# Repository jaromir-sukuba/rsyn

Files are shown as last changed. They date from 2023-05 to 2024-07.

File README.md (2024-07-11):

# What is in this repository?
Here is the complete set of design files, BOM, source files, test results and other resources that I used in the process of building a simple resistance synthesizer.

# What is resistance synthesizer?
A resistance synthesizer is a device allowing the emulation of a resistance or (nearly) any value for use in control and test instrumentation. It can emulate resistive components like resistive temperature devices (thermistors, platinum sensors) or other resistive sensors, too. There are commercial instruments that do this task, but they are often way outside the average hobby budget. Therefore, I decided to build one.

This project demonstrates a simple resistance synthesizer device built around a high-precision digital-to-analog converter (DAC) that is controlled by a microcontroller, allowing communication with a computer to control and calibrate the instrument, allowing integration into automated test setups. As standard in test equipment, the analog portion of the instrument is isolated from the digital portion, which makes the integration much easier as the synthesizer doesn't suffer from ground loops and is insulated from potentially dangerous voltage levels. Apart from control via USB, the instrument contains a local user interface consisting of a keypad and display.
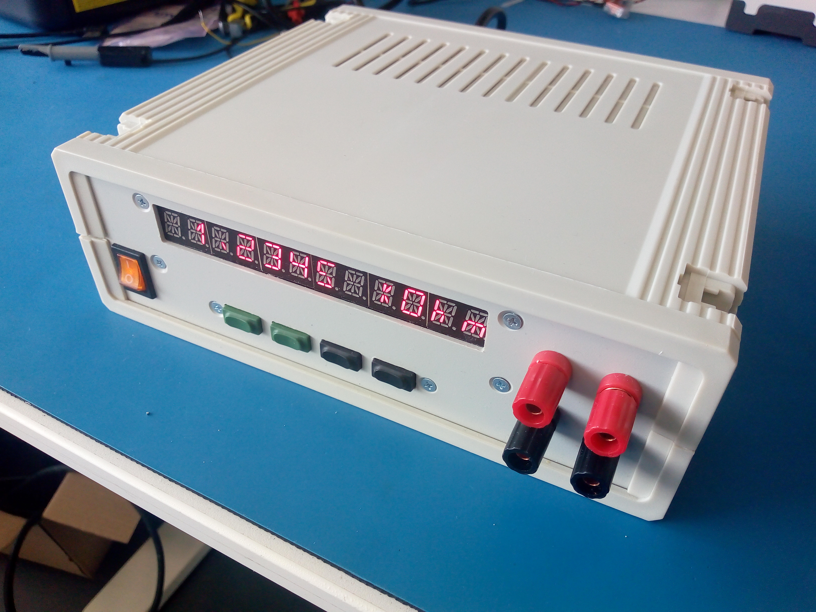
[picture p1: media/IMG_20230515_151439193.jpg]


# How does resistance synthesis work?
Reistance synthesis can be done in numerous ways. The obvious one is a network of resistors and relays to switch the desired value. The number of relays and resistors can be minimized by varying exponential values and switching in binary code patterns. That would employ resistor values of 1R-2R-4R-8R-16,  etc., and an appropriate switching pattern allowing the resistor to be included or excluded from the circuit. This approach is quite straightforward but has a few issues. Contact resistance is included in the resistor value and can matter, especially on the low end of the range (unless a four-wire arrangement is used, which can solve most of the contact problems); the contact resistance may change over the relay lifetime and other environmental factors. Furthermore, switching takes time, may be acoustically noisy, and causes relay contact wear.
More elegant is the electrical resistance adjustment. Digital potentiometers may be adequate for many uses, but they usually suffer from low resolution and low precision. While those can be a perfect fit for many applications, my idea of a resistance synthesizer requires somehow a more nuanced approach.
Fortunately, there are other ways to emulate the resistance, reducing the problem to current sensing and voltage generation, both of which can be done relatively easily and with much higher precision than the digital potentiometer can offer.
The principle is simple and this picture demonstrates this approach. 
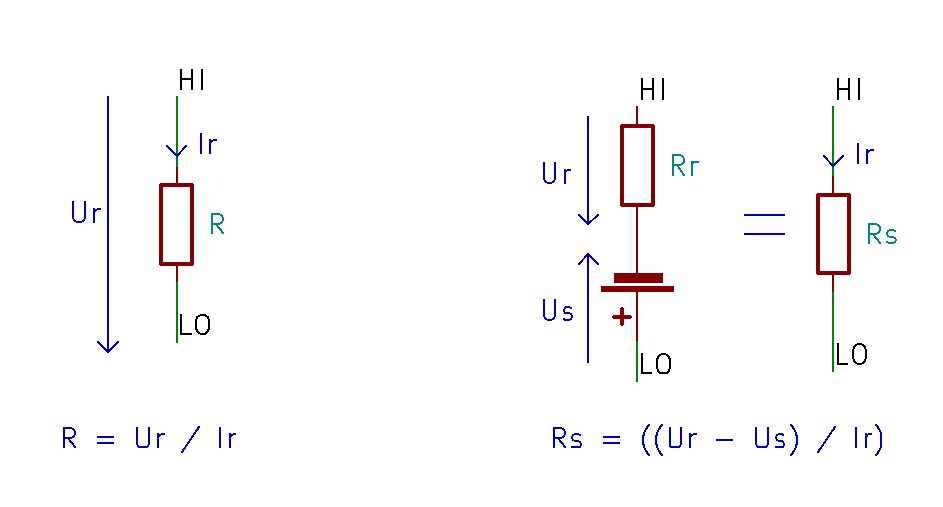
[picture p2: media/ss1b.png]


The left side of the picture captures voltage and current in a simple circuit with a resistor, following Ohm's law. Should we include voltage source U in series with the resistor, the apparent resistance of the circuit changes, following the formula on the right side of the picture. If the Us is derived from the current Ir, the resulting resistance value is invariant of the current Ir, so that the circuit behaves like a resistor with apparent resistance Rs between zero (Us = Ir x Rr) and Rr (Us = 0). 

Second picture depicts this idealized schematic in a way that somehow resembles the circuit in my resistance synthesizer. 
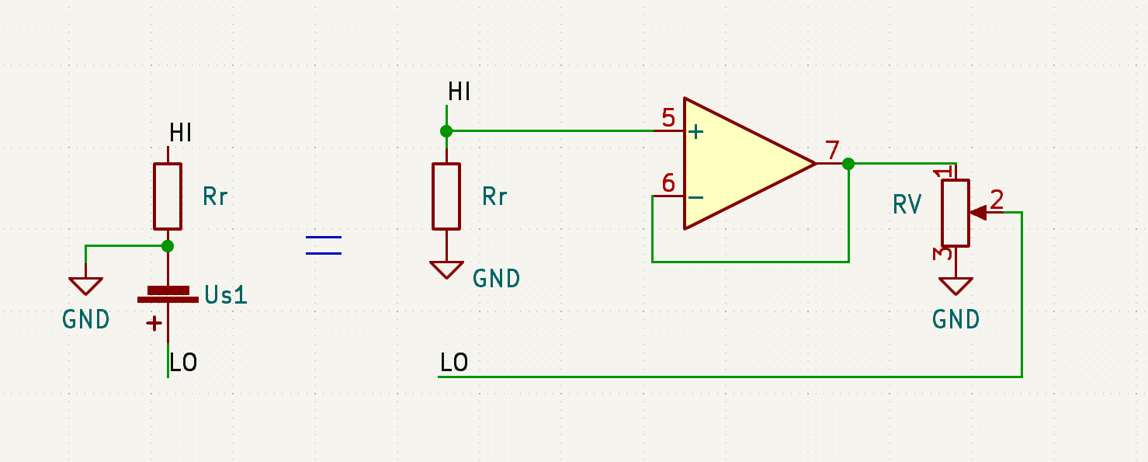
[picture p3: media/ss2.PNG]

The voltage on Rr is brought to a voltage follower (so that Ir isn't influenced by following circuits) and subsequently to a potentiometer, allowing it to regulate the synthesized resistance value. This circuit has the advantage of a potentiometer acting like a grounded voltage divider, so it can be substituted by a multiplying DAC, in this case LTC2756.

# Instrument overview
Schematic sheet 'Interconnect' depicts top-level schematics and internal instrument wiring.
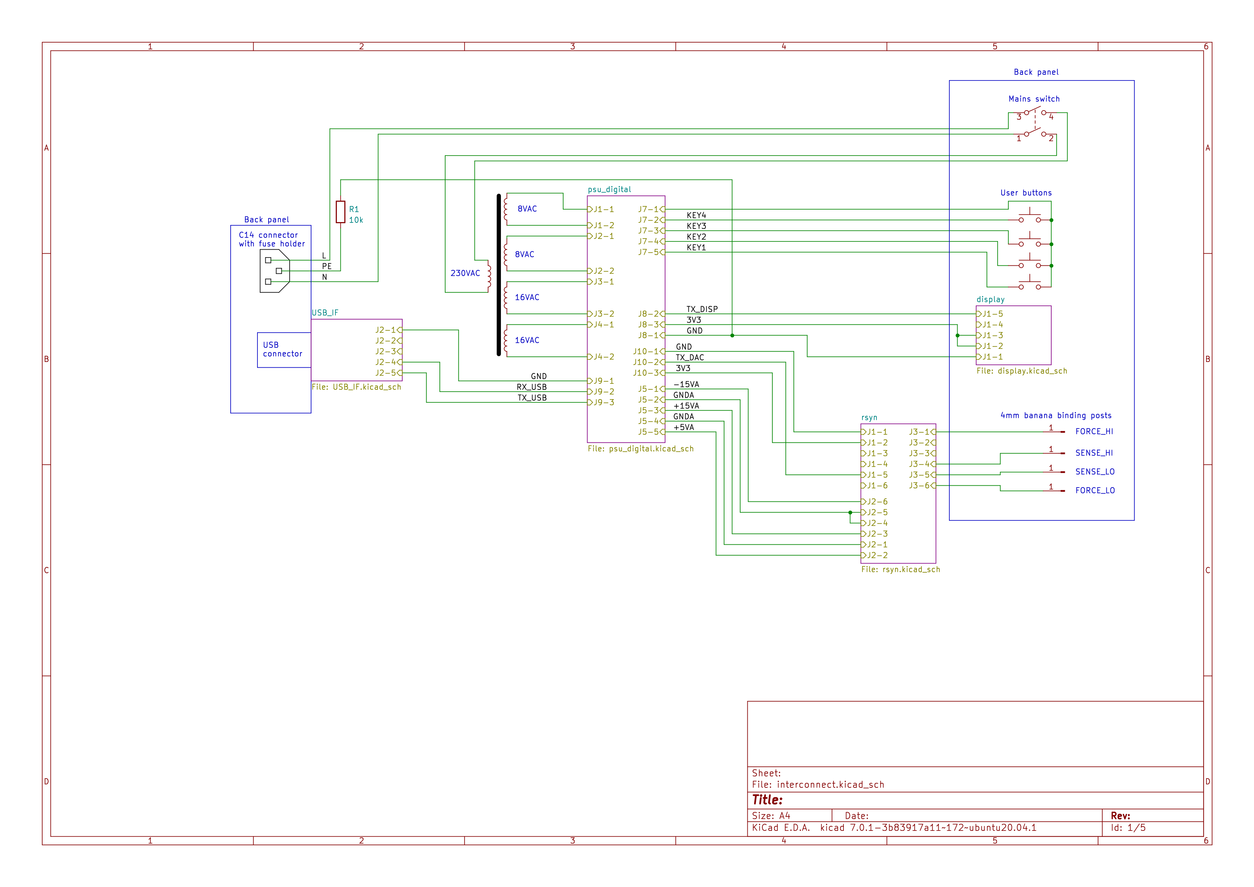
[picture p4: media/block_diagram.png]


## Resistance synthesizer board
Reference resistors R19 and R29/30 are switched using DG442 analog switches U11C and U11D. There are options to change the gain of the reference resistor amplifier (R20, R24, R28, and U7B, U11A, and U11B) and DAC amplifier (R8, R9, R10, and switches U7A, U7C, and U7D), but those aren't used in the current firmware, so that U7A and U7B are switched continuously.
U4 is the heart of the resistance synthesizer board. It works in a more-or-less datasheet configuration, with one interesting point: its reference voltage is switchable by zero-ohm resistors R2 and R3 (only one is installed). When R2 is populated, the output works in the range 0..5 V and is useful for testing the DAC. In this mode, the circuit doesn't work as a resistance synthesizer. When R3 is installed instead of R2, the reference voltage is derived from the resistance drop on a reference resistor (refer to Picture #2), and the circuit works as a resistance synthesizer.
The remaining parts of the PCB are just support functions for the DAC. Microcontroller U10 acts as a UART-DAC bridge, converting ASCII commands from serial lines to DAC SPI control packets and analog switch actions. U3 acts as a digital isolator, allowing the digital and analog boards to be separated electrically.

## Display board
Three SCT2024 shift registers with constant current drivers are chained into a 48-bit-long string. Six pieces of dual starburst LED displays are multiplexed in a 1:4 multiplex ratio by the microcontroller U7. This microcontroller communicates via serial line and transforms single ASCII commands into text readable on the display.

## Digital and PSU boards
U5 on this board acts as the main controlling element of the device. It talks to internal microcontrollers (on the resistance synthesizer board and display board) as well as external communication channels via USB. Apart from that, it reads the keyboard to allow direct user control. The majority of the complexity of this part lies in firmware, available on GitHub.
PSU is relatively straight-forward. Both analog and digital sections are fed from separate transformer windings, each with a diode rectifier and voltage regulator. In the case of the digital section, I opted for a Murata OKI-78-SR-33 switching regulator to cut down on heat generated in the PSU.

# Physical construction
Resistance synthesizers and display boards were designed as 4-layer PCBs in KiCAD. Digital PSU and keypad boards were simple enough to be made on a perfboard.
All electrical components are mounted into a CP-15-32 enclosure with custom milled front and back panels. Construction is obvious from the photos.
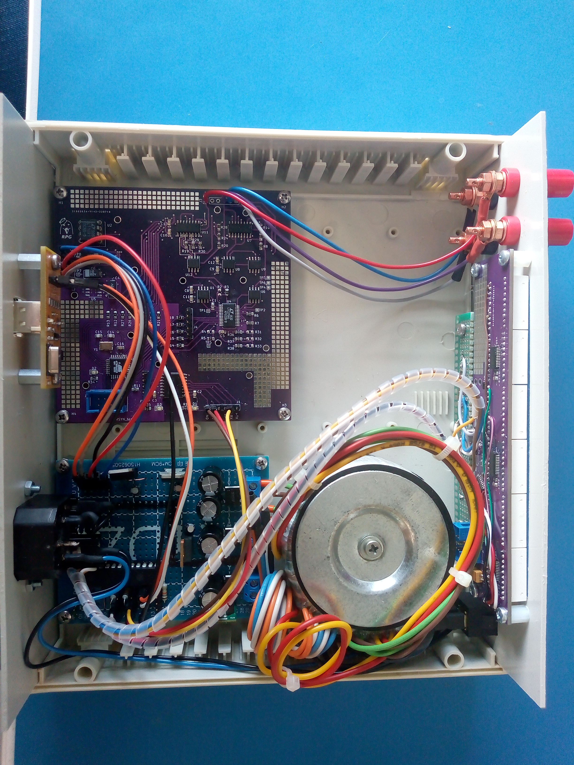
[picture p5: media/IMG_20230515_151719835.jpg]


# Instrument operation
It is operated using either a local interface or serial commands. For the local interface, keys 1 and 2 select the digit to be modified, and keys 3 and 4 perform incrementation or decrementation of the digit. The digit to be modified blinks for approximately 4 seconds. Pressing keys 1 and 2 simultaneously changes the range (10 and 100 kOhm ranges).
For the serial interface, the following commands are implemented in current firmware:

### idn
returns instrument identification
PC->Instrument: idn<LF>
Instrument->PC: RSYN Ver 1.00<LF>

### srv
set resistance value
PC->Instrument: srv 1.234LF>
Instrument->PC: srv 1.234LF>

### grv
set resistance value
PC->Instrument: grv<LF>
Instrument->PC: grv 1.234LF>

### srr
set resistance range (0: 0-10 kOhm; 1: 0-100 kOhm)
PC->Instrument: srr 1LF>
Instrument->PC: srr 1LF>

### grr
Get the resistance range (0: 0-10 kOhm; 1: 0-100 kOhm).
PC->Instrument: grr<LF>
Instrument->PC: grr 1LF>

### scc 
Set the calibration coefficient (the first argument is the coefficient number, the second is the coefficient).
PC->Instrument: scc 2, 3.456LF>
Instrument->PC: scc 2, 3.456LF>

### gcc 
Get the calibration coefficient (the argument is the coefficient number).
PC->Instrument: gcc 2LF>
Instrument->PC: gcc 2, 3.456LF>

### gcd
get a calibration dump
PC->Instrument: gcd<LF>
Instrument->PC: gcc [followed by calibration constants on each line] <LF>

### wmc
write calibration coefficient (into EEPROM memory; previous calibration is overwritten)
PC->Instrument: wcc<LF>
Instrument->PC: wcc<LF>

After first powering up, default calibration constants 0 and 12345 are loaded for offset and gain, respectively. The user needs to replace those constants with valid ones obtained by calibration. For calibration, a ohmmeter, usually in a form of multimeter has to be used. The precision of the resistance synthesizer is determined by he meter used for adjustment. On the other hand, thermal and long time drift is given by design and construction of the device.
The calibration procedure is as follows:
1. Turn on the calibration meter and resistance synthesizer, connect the appropriate leads, and let them warm up (typical precision meters do have a few hours of warmup required).
2, set the meter to the 10 kOhm manual range, set the synthesizer to the 10 kOhm range, and set the synthesizer to 50 kOhm. Adjust the offset to range 0 so that the meter correctly displays 50 ohms.
3. Set the synthesizer to 10 kOhm. Adjust gain at range 0 so that the meter correctly displays 10 kOhm.
4. Repeat steps 2 and 3 if needed.
5, do the same as step 2 on 100 kOhm ranges and adjust offset at range 1.
6. Do the same as step 3, with a 100 kOhm value, and adjust gain at range 1.
7. Repeat steps 4 and 5 if needed.
8. Issue the wmc command to overwrite previous calibration values in the EEPROM.

## Verification
For parameter verification, I performed two tests: a linearity check and short-term stability. 
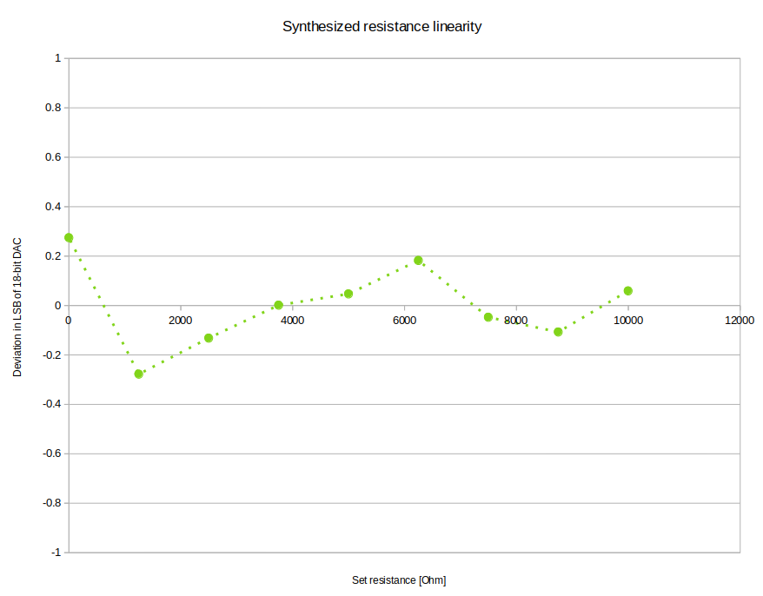
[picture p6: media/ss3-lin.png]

For the linearity test, I set the values of the DAC converter to values from 0 to 262143 in increments of 32768. I measured the resitance values using an HP34401A multimeter and calculated the difference from the linear fit of the values, expressed in the least significant digits of the value. As apparent from the graph, the typical deviation from linearity is around 0.2 LSB, indicating that the used DAC has very good linearity, and apart from that, linearity isn't degraded by the analog functionality (chosen opamps and reference resistors).
Short-term stability: I measured the value of resistance set to 5 kOhm over the course of one hour. The value was stable within the 20 mOhm range. 
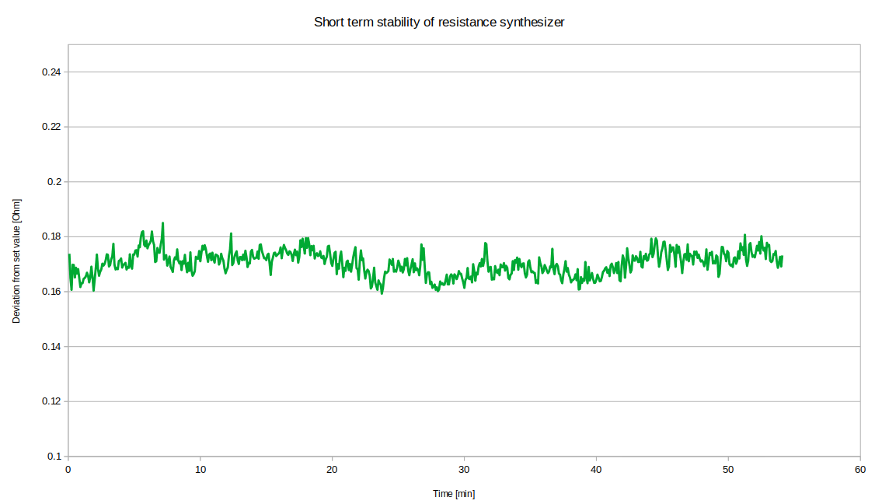
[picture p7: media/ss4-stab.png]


# Resources
A video showing the synthesizer in operation is at https://youtu.be/5EVBY4_3-oE

# Resume
This resistance synthesizer is not a very common target of DIY designs, but nonetheless, it's a useful tool for automatic calibration of test and measurement instruments or as a general-purpose tool for testing and adjusting multimeters, controllers, and similar apparatus.

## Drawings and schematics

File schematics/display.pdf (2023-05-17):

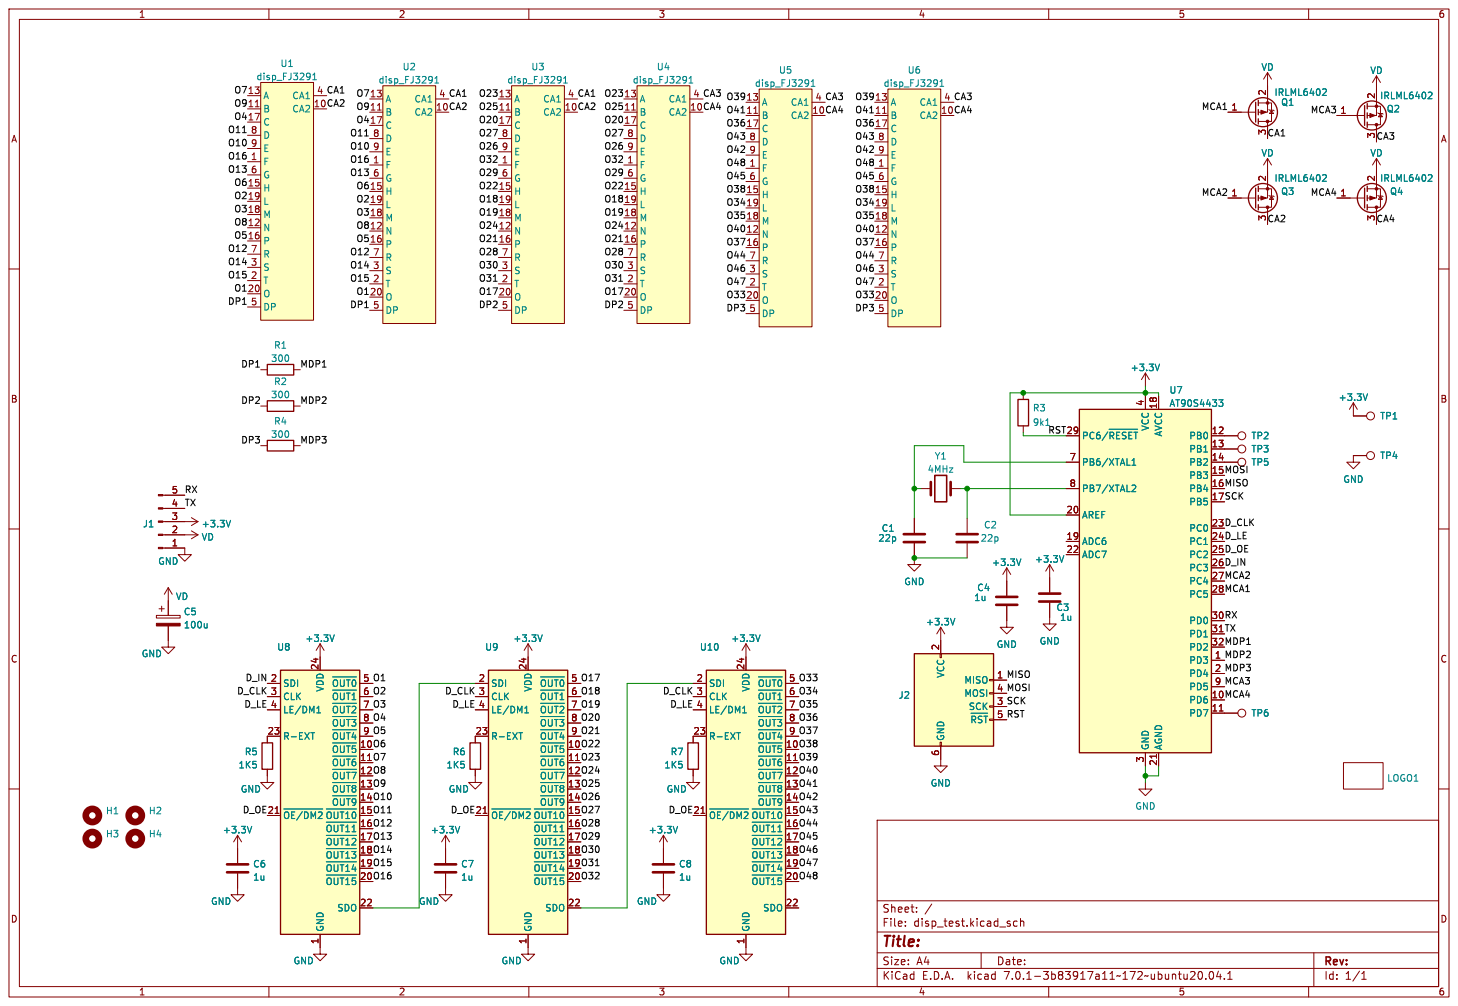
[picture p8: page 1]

2 SCK 3 MOSI 4 ~{RST}5 GND

1 ~{OUT5} 10 ~{OUT6} 11 ~{OUT7} 12 ~{OUT8} 13 ~{OUT9} 14 ~{OUT10}15 ~{OUT11}16 ~{OUT12}17 ~{OUT13}18 ~{OUT14}19 SDI 2 ~{OUT15}20 ~{OE/DM2} 21 SDO 22 R-EXT 23 VDD 24 CLK 3

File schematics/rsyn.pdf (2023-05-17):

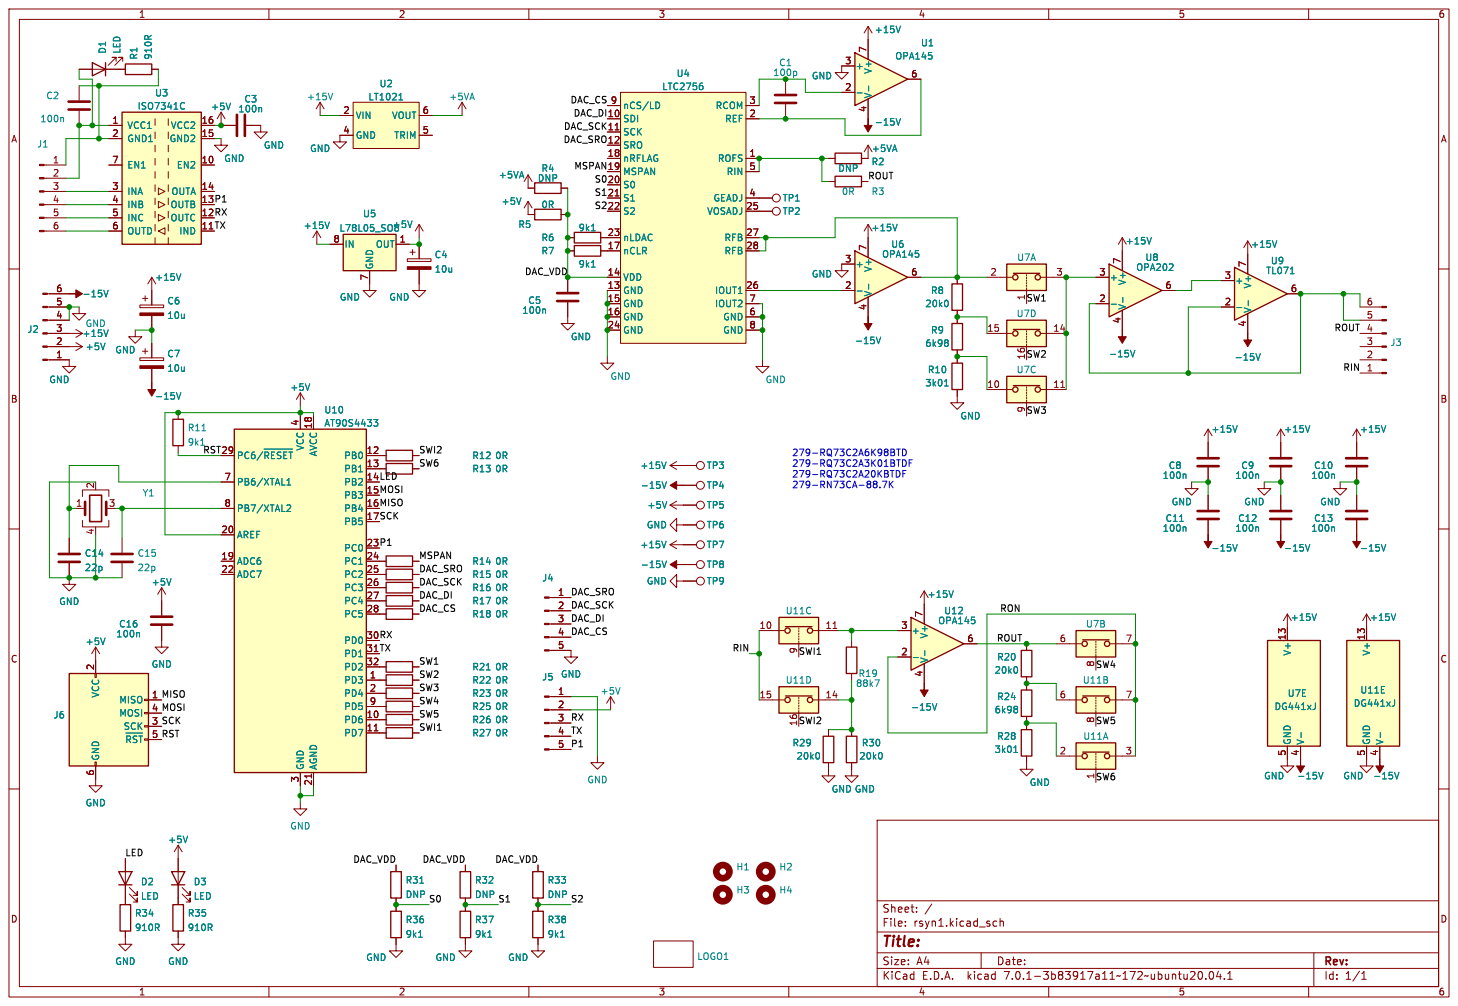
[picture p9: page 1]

IND 11 OUTC 12 OUTB 13 OUTA 14 GND2 15 VCC2 16 GND1 2

2 SCK 3 MOSI 4 ~{RST}5 GND

5 GND -15V GND -15V GND GND

Id: 1/1 Title: File: rsyn1.kicad_sch Sheet: /

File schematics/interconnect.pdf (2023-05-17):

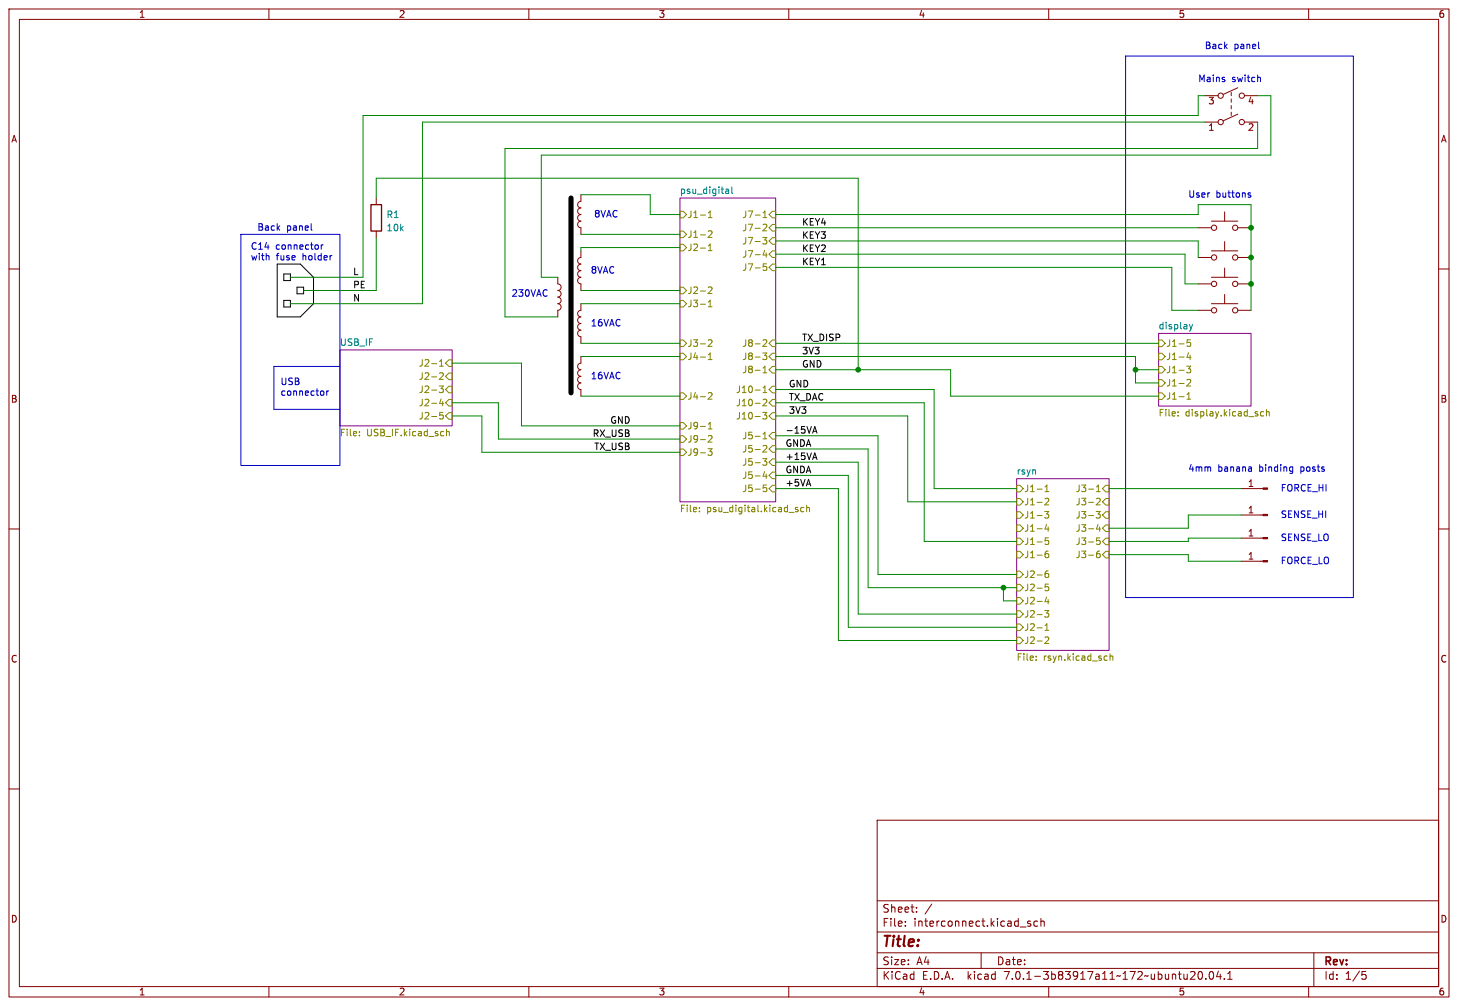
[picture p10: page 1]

C14 connector with fuse holder USB

Id: 1/5 Title: File: interconnect.kicad_sch Sheet: /

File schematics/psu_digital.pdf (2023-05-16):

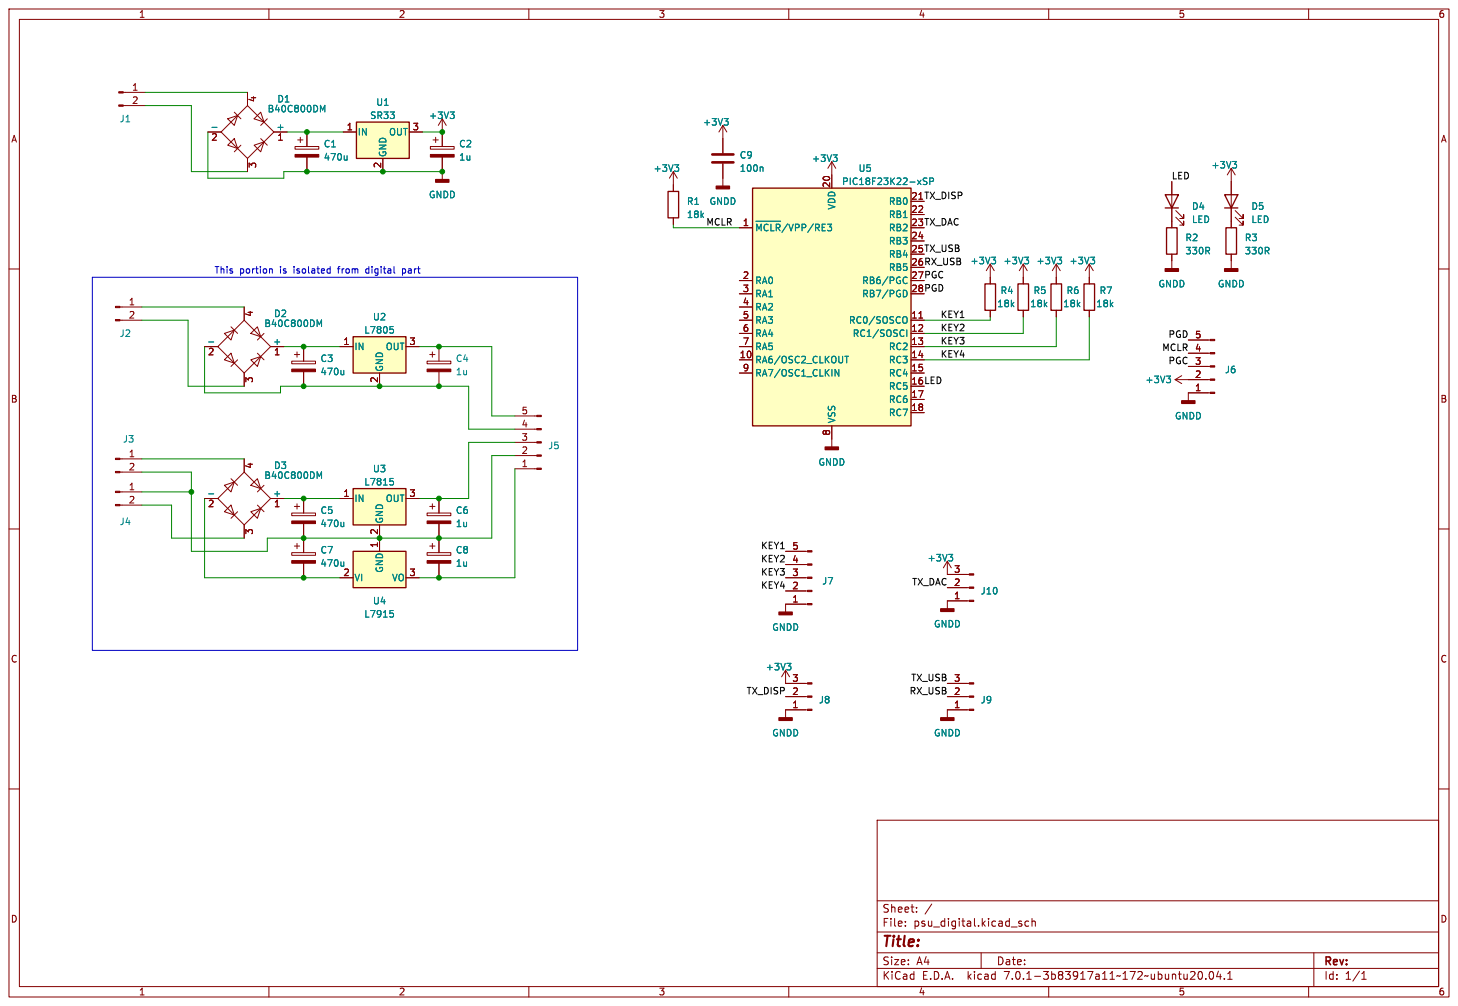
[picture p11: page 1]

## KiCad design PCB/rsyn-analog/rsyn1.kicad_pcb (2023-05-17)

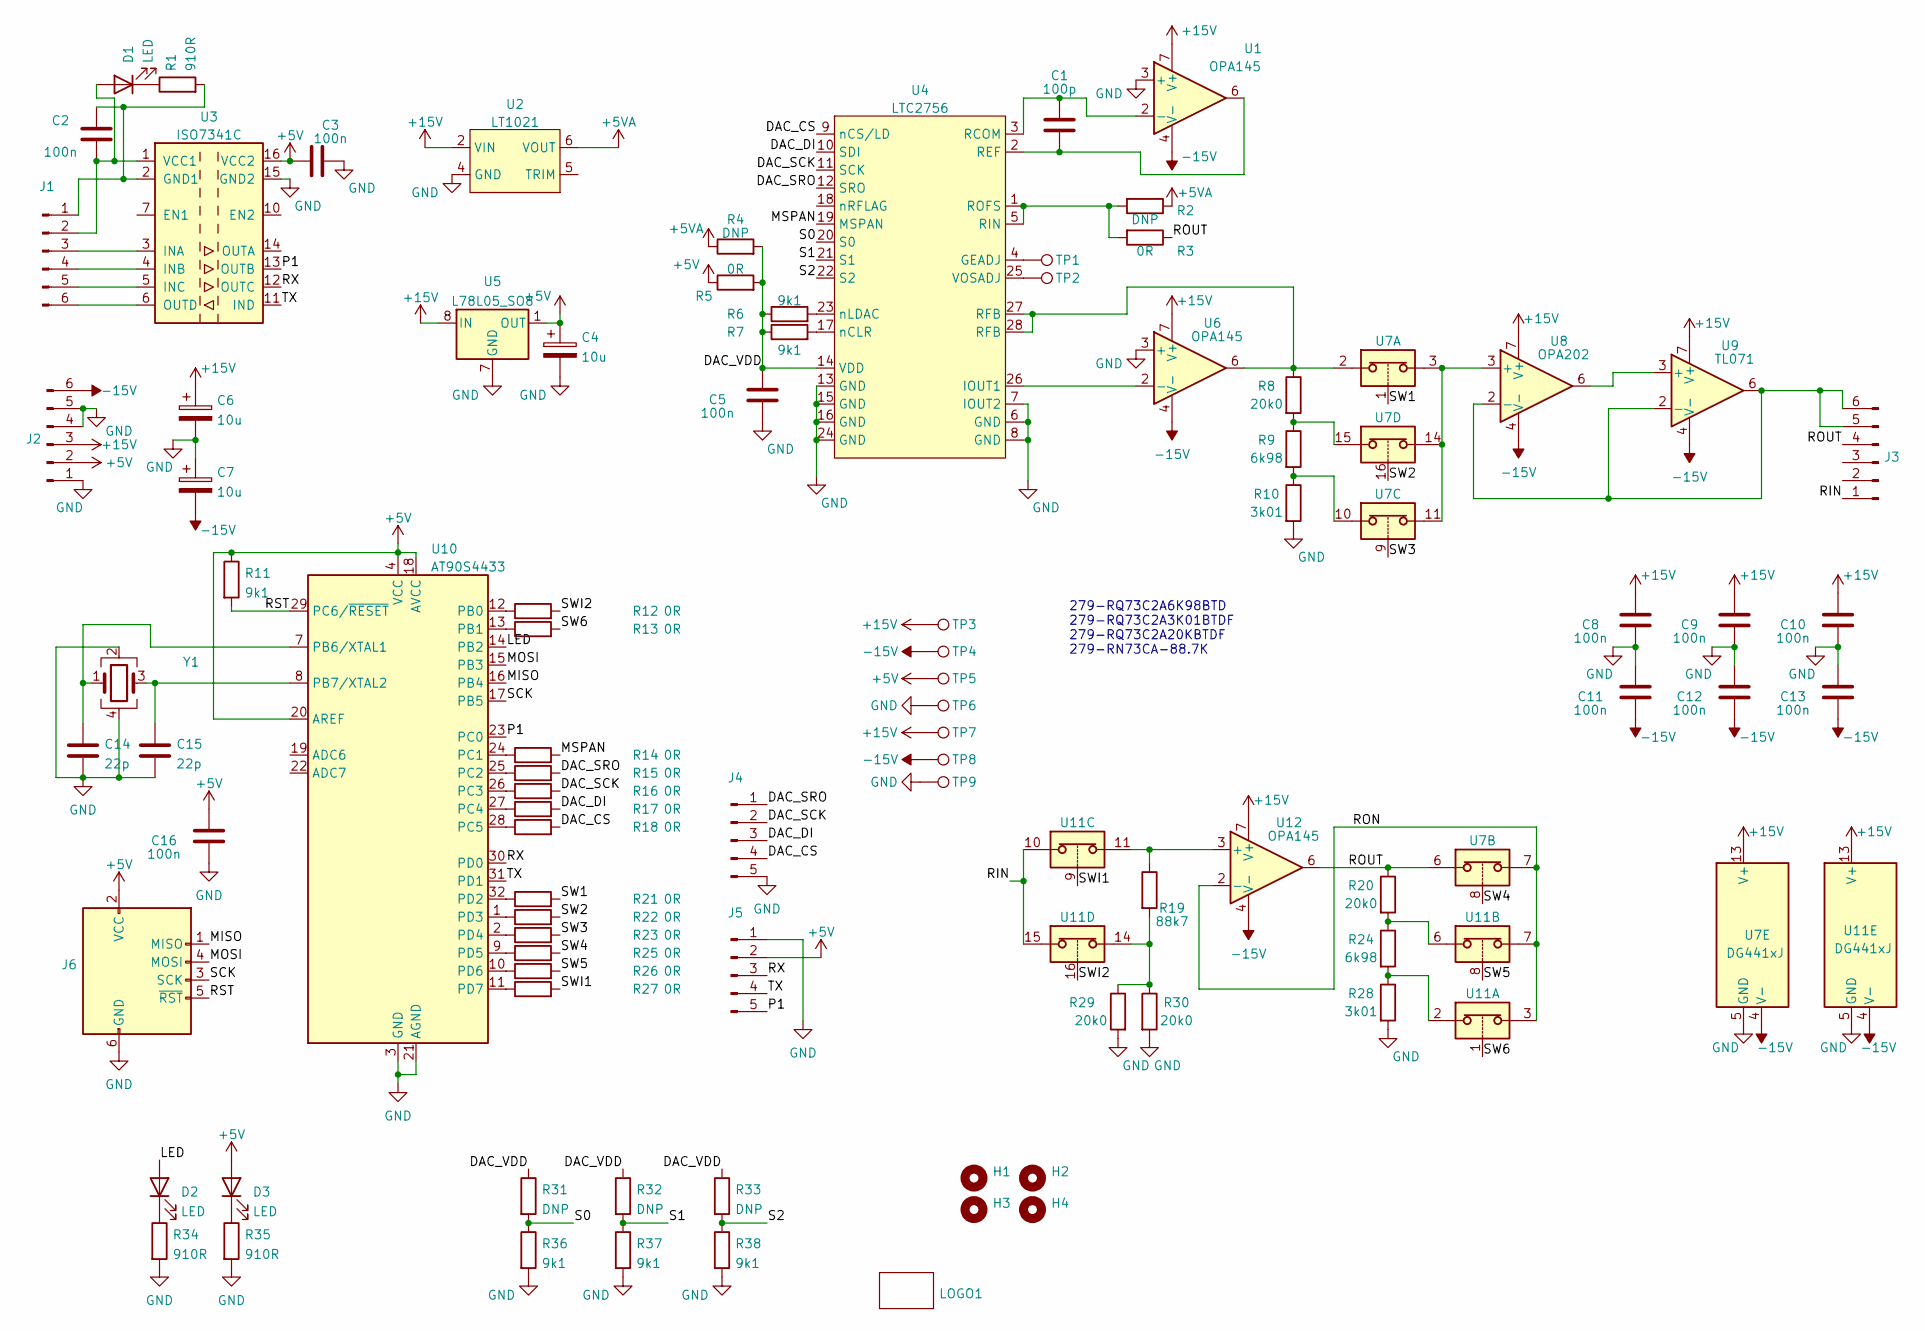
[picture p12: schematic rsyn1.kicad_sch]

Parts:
C1: 100p; C_0805_2012Metric_Pad1.18x1.45mm_HandSolder
C2, C3, C5, C8, C9, C10, C11, C12, C13, C16: 100n; C_0805_2012Metric_Pad1.18x1.45mm_HandSolder
C4, C6, C7: 10u; CP_EIA-6032-28_Kemet-C_Pad2.25x2.35mm_HandSolder
C14, C15: 22p; C_0805_2012Metric_Pad1.18x1.45mm_HandSolder
D1, D2, D3: LED; LED_0805_2012Metric_Pad1.15x1.40mm_HandSolder
H1, H2, H3, H4: MountingHole; MountingHole_3.2mm_M3_DIN965_Pad
J1, J2, J3: Conn_01x06_Male; PinHeader_1x06_P2.54mm_Vertical
J4, J5: Conn_01x05_Male; PinHeader_1x05_P2.54mm_Vertical
J6: AVR-ISP-6; IDC-Header_2x03_P2.54mm_Vertical
LOGO1: logo_generic; logo_rpg7x9
R1, R34, R35: 910R; R_0805_2012Metric_Pad1.20x1.40mm_HandSolder
R2, R4, R31, R32, R33: DNP; R_0805_2012Metric_Pad1.20x1.40mm_HandSolder
R3, R5, R12, R13, R14, R15, R16, R17, R18, R21, R22, R23, R25, R26, R27: 0R; R_0805_2012Metric_Pad1.20x1.40mm_HandSolder
R6, R7, R11, R36, R37, R38: 9k1; R_0805_2012Metric_Pad1.20x1.40mm_HandSolder
R8, R20, R29, R30: 20k0; R_0805_2012Metric_Pad1.20x1.40mm_HandSolder
R9, R24: 6k98; R_0805_2012Metric_Pad1.20x1.40mm_HandSolder
R10, R28: 3k01; R_0805_2012Metric_Pad1.20x1.40mm_HandSolder
R19: 88k7; R_0805_2012Metric_Pad1.20x1.40mm_HandSolder
TP1, TP2, TP3, TP4, TP5, TP6, TP7, TP8, TP9: TestPoint; TestPoint_Pad_1.0x1.0mm
U1, U6, U12: OPA145; SOIC-8_3.9x4.9mm_P1.27mm
U2: LT1021; DIP-8_W7.62mm_Socket
U3: ISO7341C; SOIC-16W_7.5x10.3mm_P1.27mm
U4: LTC2756; SSOP-28_5.3x10.2mm_P0.65mm
U5: L78L05_SO8; SOIC-8_3.9x4.9mm_P1.27mm
U7, U11: DG441xJ; SO-16_3.9x9.9mm_P1.27mm
U8: OPA202; SOIC-8_3.9x4.9mm_P1.27mm
U9: TL071; SOIC-8_3.9x4.9mm_P1.27mm
U10: AT90S4433; TQFP-32_7x7mm_P0.8mm
Y1: Crystal_GND24; Crystal_SMD_Abracon_ABM3B-4Pin_5.0x3.2mm

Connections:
+5V: C3.1, C4.1, C16.2, D3.2 (A), J2.2, J5.2, J6.2 (VCC), R5.1, R11.1, TP5.1, U3.16 (VCC2), U5.1 (OUT), U10.4 (VCC), U10.6 (VCC), U10.18 (AVCC), U10.20 (AREF)
+5VA: R2.1, R4.1, U2.6 (VOUT)
+15V: C6.1, C8.2, C9.2, C10.2, J2.3, TP3.1, TP7.1, U1.7 (V+), U2.2 (VIN), U5.8 (IN), U6.7 (V+), U7.13 (V+), U8.7 (V+), U9.7 (V+), U11.13 (V+), U12.7 (V+)
-15V: C7.2, C11.1, C12.1, C13.1, J2.6, TP4.1, TP8.1, U1.4 (V-), U6.4 (V-), U7.4 (V-), U8.4 (V-), U9.4 (V-), U11.4 (V-), U12.4 (V-)
/DAC_CS: J4.4, R18.2, U4.9 (nCS/LD)
/DAC_DI: J4.3, R17.2, U4.10 (SDI)
/DAC_SCK: J4.2, R16.2, U4.11 (SCK)
/DAC_SRO: J4.1, R15.2, U4.12 (SRO)
/DAC_VDD: C5.2, R4.2, R5.2, R6.1, R7.1, R31.1, R32.1, R33.1, U4.14 (VDD)
/LED: D2.2 (A), U10.14 (PB2)
/MISO: J6.1 (MISO), U10.16 (PB4)
/MOSI: J6.4 (MOSI), U10.15 (PB3)
/MSPAN: R14.2, U4.19 (MSPAN)
/P1: J5.5, U3.13 (OUTB), U10.23 (PC0)
/RIN: J3.1, U11.10, U11.15
/RON: U7.7, U11.3, U11.7, U12.2 (-)
/ROUT: J3.4, R3.1, R20.1, U7.6, U12.6
/RST: J6.5 (~RST), R11.2, U10.29 (PC6/~RESET)
/RX: J5.3, U3.12 (OUTC), U10.30 (PD0)
/S0: R31.2, R36.1, U4.20 (S0)
/S1: R32.2, R37.1, U4.21 (S1)
/S2: R33.2, R38.1, U4.22 (S2)
/SCK: J6.3 (SCK), U10.17 (PB5)
/SW1: R21.2, U7.1
/SW2: R22.2, U7.16
/SW3: R23.2, U7.9
/SW4: R25.2, U7.8
/SW5: R26.2, U11.8
/SW6: R13.2, U11.1
/SWI1: R27.2, U11.9
/SWI2: R12.2, U11.16
/TX: J5.4, U3.11 (IND), U10.31 (PD1)
GND: C3.2, C4.2, C5.1, C6.2, C7.1, C8.1, C9.1, C10.1, C11.2, C12.2, C13.2, C14.2, C15.2, C16.1, J2.1, J2.4, J2.5, J4.5, J5.1, J6.6 (GND), R10.2, R28.2, R29.2, R30.2, R34.2, R35.2, R36.2, R37.2, R38.2, TP6.1, TP9.1, U1.3 (+), U2.4 (GND), U3.9 (GND2), U3.15 (GND2), U4.6 (GND), U4.7 (IOUT2), U4.8 (GND), U4.13 (GND), U4.15 (GND), U4.16 (GND), U4.24 (GND), U5.2 (GND), U5.3 (GND), U5.6 (GND), U5.7 (GND), U6.3 (+), U7.5 (GND), U10.3 (GND), U10.5 (GND), U10.21 (AGND), U11.5 (GND), Y1.2, Y1.4
unnamed: C2.1, D1.2 (A), J1.2, U3.1 (VCC1)
unnamed: D1.1 (K), R1.1
unnamed: D2.1 (K), R34.1
unnamed: D3.1 (K), R35.1
unnamed: C2.2, J1.1, R1.2, U3.2 (GND1), U3.8 (GND1)
unnamed: J1.3, U3.3 (INA)
unnamed: J1.4, U3.4 (INB)
unnamed: J1.5, U3.5 (INC)
unnamed: J1.6, U3.6 (OUTD)
unnamed: J3.5, J3.6, U8.2 (-), U9.2 (-), U9.6
unnamed: R8.1, U4.27 (RFB), U4.28 (RFB), U6.6, U7.2
unnamed: R8.2, R9.1, U7.15
unnamed: R9.2, R10.1, U7.10
unnamed: R19.2, R29.1, R30.1, U11.14
unnamed: R20.2, R24.1, U11.6
unnamed: R24.2, R28.1, U11.2
unnamed: C1.2, U1.2 (-), U4.3 (RCOM)
unnamed: TP1.1, U4.4 (GEADJ)
unnamed: U4.26 (IOUT1), U6.2 (-)
unnamed: C1.1, U1.6, U4.2 (REF)
unnamed: R2.2, R3.2, U4.1 (ROFS), U4.5 (RIN)
unnamed: TP2.1, U4.25 (VOSADJ)
unnamed: R7.2, U4.17 (nCLR)
unnamed: R6.2, U4.23 (nLDAC)
unnamed: U7.3, U7.11, U7.14, U8.3 (+)
unnamed: U8.6, U9.3 (+)
unnamed: R12.1, U10.12 (PB0)
unnamed: R13.1, U10.13 (PB1)
unnamed: C14.1, U10.7 (PB6/XTAL1), Y1.1
unnamed: C15.1, U10.8 (PB7/XTAL2), Y1.3
unnamed: R14.1, U10.24 (PC1)
unnamed: R15.1, U10.25 (PC2)
unnamed: R16.1, U10.26 (PC3)
unnamed: R17.1, U10.27 (PC4)
unnamed: R18.1, U10.28 (PC5)
unnamed: R21.1, U10.32 (PD2)
unnamed: R22.1, U10.1 (PD3)
unnamed: R23.1, U10.2 (PD4)
unnamed: R25.1, U10.9 (PD5)
unnamed: R26.1, U10.10 (PD6)
unnamed: R27.1, U10.11 (PD7)
unnamed: R19.1, U11.11, U12.3 (+)

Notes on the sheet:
279-RQ73C2A6K98BTD 279-RQ73C2A3K01BTDF 279-RQ73C2A20KBTDF 279-RN73CA-88.7K

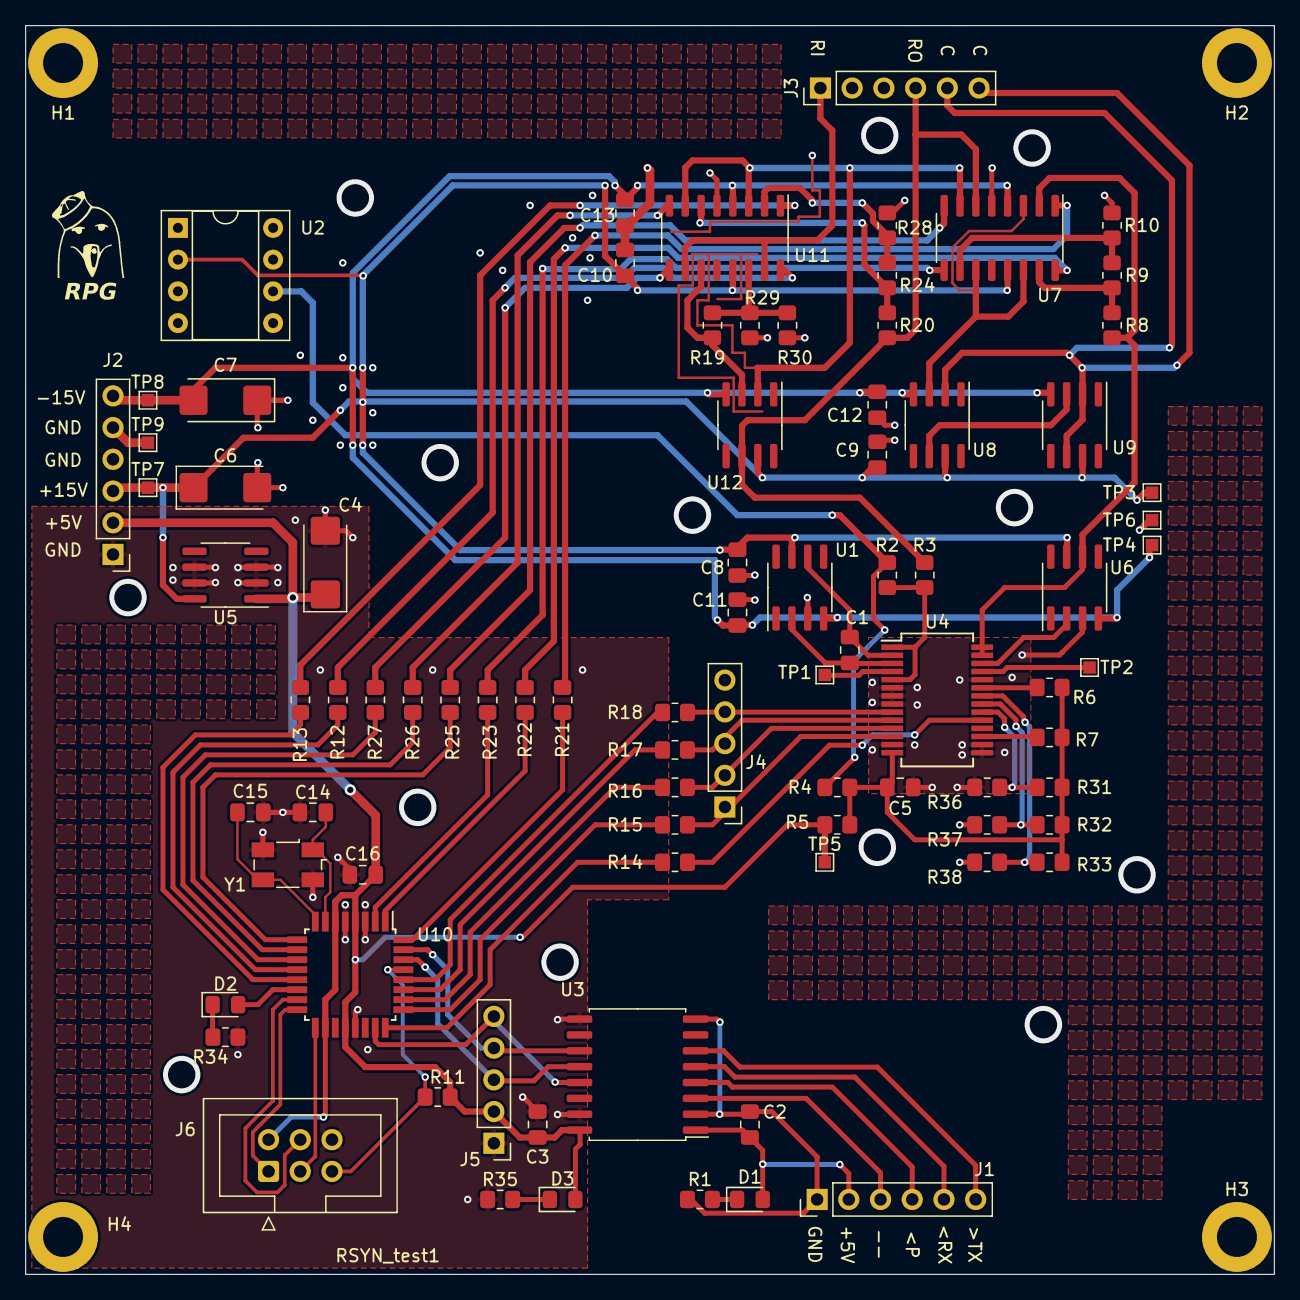
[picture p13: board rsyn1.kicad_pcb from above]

Board: 4 copper layers, 100.0 x 100.0 mm, 90 parts (0 on the bottom side), 75 nets.

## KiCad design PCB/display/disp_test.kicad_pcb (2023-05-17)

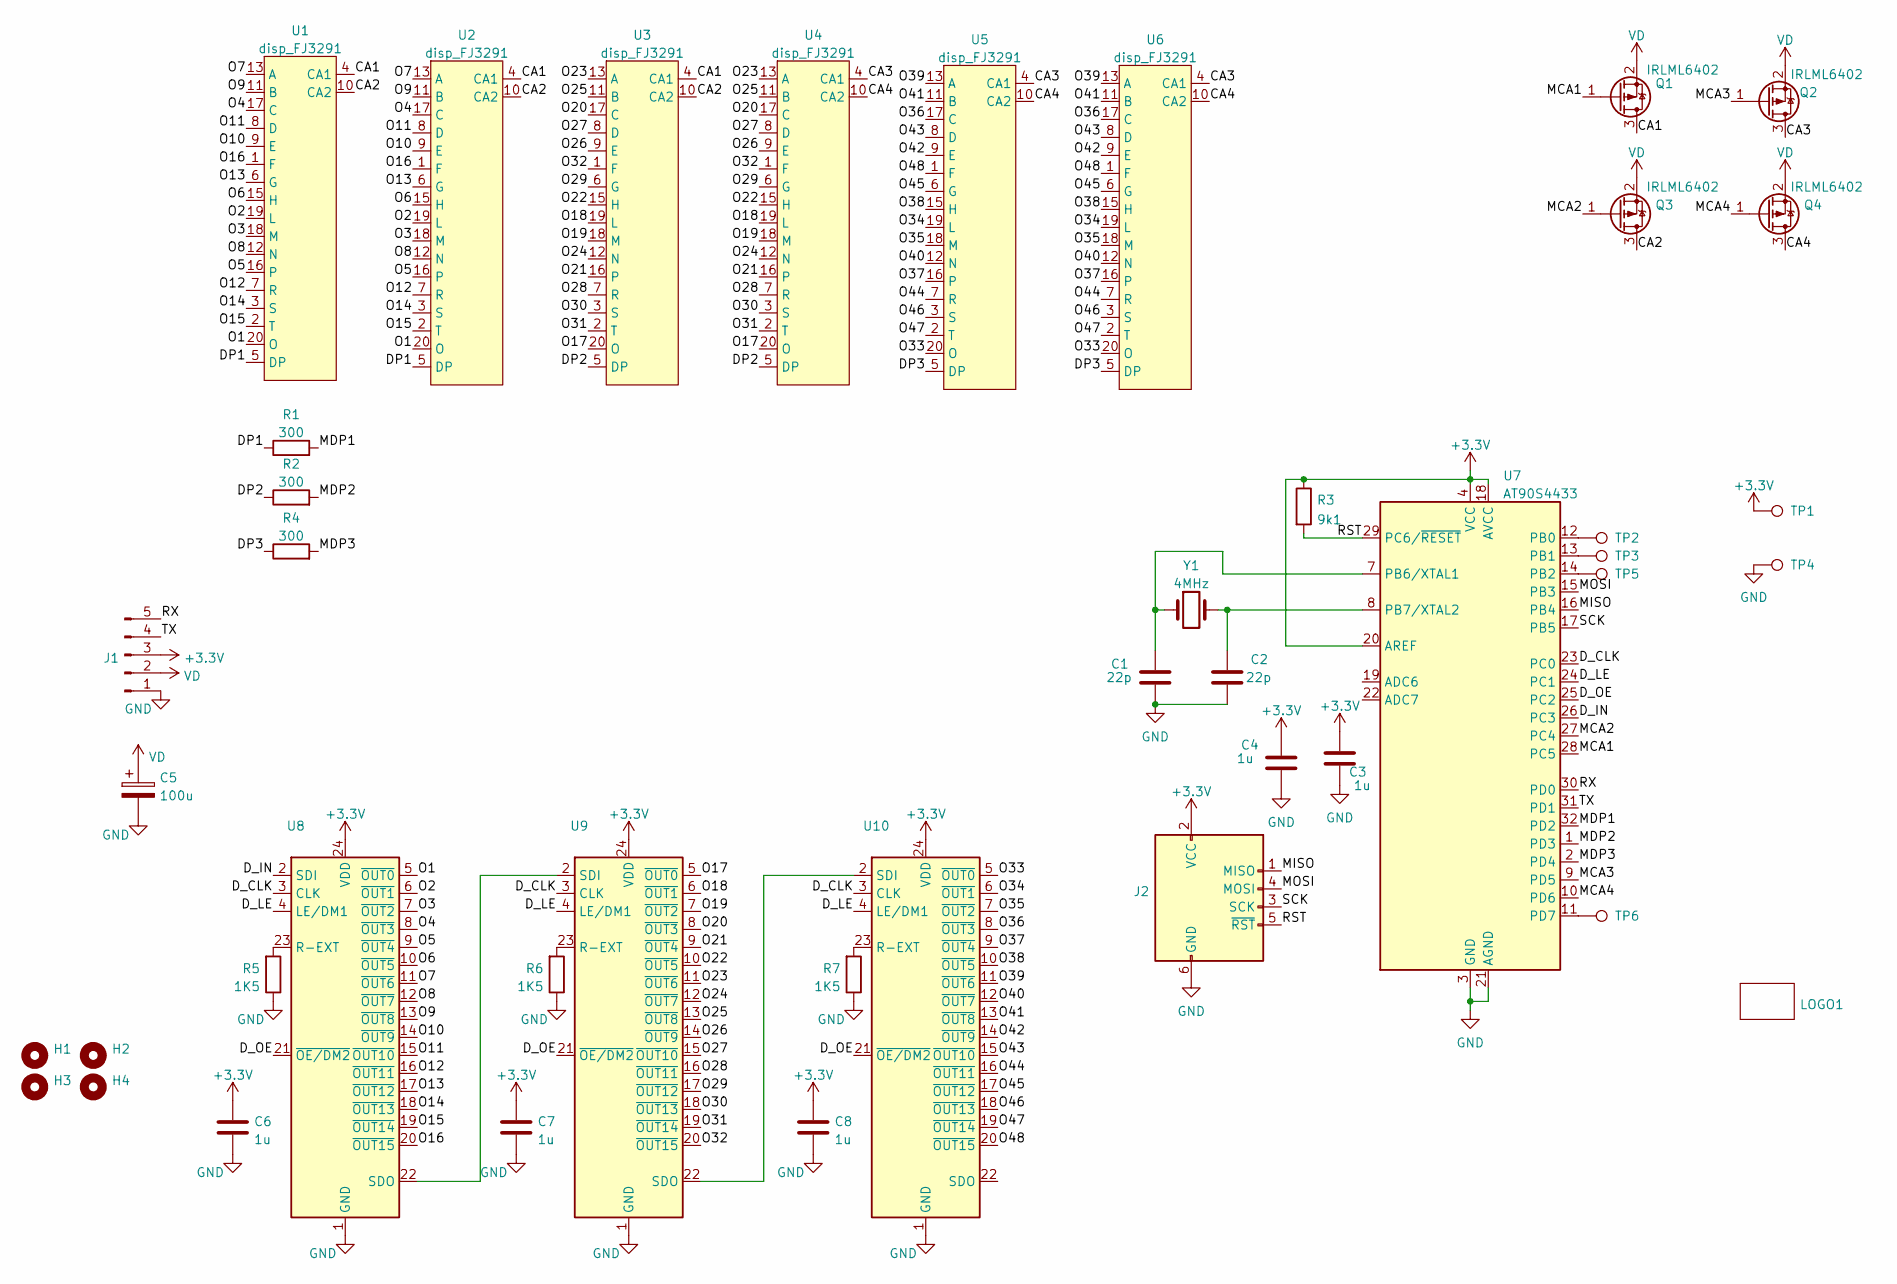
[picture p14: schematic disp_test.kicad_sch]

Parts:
C1, C2: 22p; C_0805_2012Metric_Pad1.18x1.45mm_HandSolder
C3, C4, C6, C7, C8: 1u; C_0805_2012Metric_Pad1.18x1.45mm_HandSolder
C5: 100u; CP_EIA-7343-31_Kemet-D_Pad2.25x2.55mm_HandSolder
H1, H2, H3, H4: MountingHole; MountingHole_3.2mm_M3_DIN965_Pad
J1: Conn_01x05_Male; PinHeader_1x05_P2.54mm_Vertical
J2: AVR-ISP-6; IDC-Header_2x03_P2.54mm_Vertical
LOGO1: logo_generic; logo_rpg7x9
Q1, Q2, Q3, Q4: IRLML6402; SOT-23
R1, R2, R4: 300; R_0805_2012Metric_Pad1.20x1.40mm_HandSolder
R3: 9k1; R_0805_2012Metric_Pad1.20x1.40mm_HandSolder
R5, R6, R7: 1K5; R_0805_2012Metric_Pad1.20x1.40mm_HandSolder
TP1, TP2, TP3, TP4, TP5, TP6: TestPoint; TestPoint_Pad_1.0x1.0mm
U1, U2, U3, U4, U5, U6: disp_FJ3291; FJ3291
U7: AT90S4433; TQFP-32_7x7mm_P0.8mm
U8, U9, U10: SSOP-24_3.9x8.7mm_P0.635mm
Y1: 4MHz; Crystal_SMD_HC49-SD_HandSoldering

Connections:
+3.3V: C3.2, C4.2, C6.1, C7.1, C8.1, J1.3, J2.2 (VCC), R3.1, TP1.1, U7.4 (VCC), U7.6 (VCC), U7.18 (AVCC), U7.20 (AREF), U8.24 (VDD), U9.24 (VDD), U10.24 (VDD)
/CA1: Q1.3 (D), U1.4 (CA1), U2.4 (CA1), U3.4 (CA1)
/CA2: Q3.3 (D), U1.10 (CA2), U2.10 (CA2), U3.10 (CA2)
/CA3: Q2.3 (D), U4.4 (CA1), U5.4 (CA1), U6.4 (CA1)
/CA4: Q4.3 (D), U4.10 (CA2), U5.10 (CA2), U6.10 (CA2)
/DP1: R1.1, U1.5 (DP), U2.5 (DP)
/DP2: R2.1, U3.5 (DP), U4.5 (DP)
/DP3: R4.1, U5.5 (DP), U6.5 (DP)
/D_CLK: U7.23 (PC0), U8.3 (CLK), U9.3 (CLK), U10.3 (CLK)
/D_IN: U7.26 (PC3), U8.2 (SDI)
/D_LE: U7.24 (PC1), U8.4 (LE/DM1), U9.4 (LE/DM1), U10.4 (LE/DM1)
/D_OE: U7.25 (PC2), U8.21 (~OE/DM2), U9.21 (~OE/DM2), U10.21 (~OE/DM2)
/MCA1: Q1.1 (G), U7.28 (PC5)
/MCA2: Q3.1 (G), U7.27 (PC4)
/MCA3: Q2.1 (G), U7.9 (PD5)
/MCA4: Q4.1 (G), U7.10 (PD6)
/MDP1: R1.2, U7.32 (PD2)
/MDP2: R2.2, U7.1 (PD3)
/MDP3: R4.2, U7.2 (PD4)
/MISO: J2.1 (MISO), U7.16 (PB4)
/MOSI: J2.4 (MOSI), U7.15 (PB3)
/O1: U1.20 (O), U2.20 (O), U8.5 (~OUT0)
/O2: U1.19 (L), U2.19 (L), U8.6 (~OUT1)
/O3: U1.18 (M), U2.18 (M), U8.7 (~OUT2)
/O4: U1.17 (C), U2.17 (C), U8.8 (~OUT3)
/O5: U1.16, U2.16, U8.9 (~OUT4)
/O6: U1.15 (H), U2.15 (H), U8.10 (~OUT5)
/O7: U1.13 (A), U2.13 (A), U8.11 (~OUT6)
/O8: U1.12 (N), U2.12 (N), U8.12 (~OUT7)
/O9: U1.11 (B), U2.11 (B), U8.13 (~OUT8)
/O10: U1.9 (E), U2.9 (E), U8.14 (~OUT9)
/O11: U1.8 (D), U2.8 (D), U8.15 (~OUT10)
/O12: U1.7 (R), U2.7 (R), U8.16 (~OUT11)
/O13: U1.6 (G), U2.6 (G), U8.17 (~OUT12)
/O14: U1.3 (S), U2.3 (S), U8.18 (~OUT13)
/O15: U1.2 (T), U2.2 (T), U8.19 (~OUT14)
/O16: U1.1 (F), U2.1 (F), U8.20 (~OUT15)
/O17: U3.20 (O), U4.20 (O), U9.5 (~OUT0)
/O18: U3.19 (L), U4.19 (L), U9.6 (~OUT1)
/O19: U3.18 (M), U4.18 (M), U9.7 (~OUT2)
/O20: U3.17 (C), U4.17 (C), U9.8 (~OUT3)
/O21: U3.16, U4.16, U9.9 (~OUT4)
/O22: U3.15 (H), U4.15 (H), U9.10 (~OUT5)
/O23: U3.13 (A), U4.13 (A), U9.11 (~OUT6)
/O24: U3.12 (N), U4.12 (N), U9.12 (~OUT7)
/O25: U3.11 (B), U4.11 (B), U9.13 (~OUT8)
/O26: U3.9 (E), U4.9 (E), U9.14 (~OUT9)
/O27: U3.8 (D), U4.8 (D), U9.15 (~OUT10)
/O28: U3.7 (R), U4.7 (R), U9.16 (~OUT11)
/O29: U3.6 (G), U4.6 (G), U9.17 (~OUT12)
/O30: U3.3 (S), U4.3 (S), U9.18 (~OUT13)
/O31: U3.2 (T), U4.2 (T), U9.19 (~OUT14)
/O32: U3.1 (F), U4.1 (F), U9.20 (~OUT15)
/O33: U5.20 (O), U6.20 (O), U10.5 (~OUT0)
/O34: U5.19 (L), U6.19 (L), U10.6 (~OUT1)
/O35: U5.18 (M), U6.18 (M), U10.7 (~OUT2)
/O36: U5.17 (C), U6.17 (C), U10.8 (~OUT3)
/O37: U5.16, U6.16, U10.9 (~OUT4)
/O38: U5.15 (H), U6.15 (H), U10.10 (~OUT5)
/O39: U5.13 (A), U6.13 (A), U10.11 (~OUT6)
/O40: U5.12 (N), U6.12 (N), U10.12 (~OUT7)
/O41: U5.11 (B), U6.11 (B), U10.13 (~OUT8)
/O42: U5.9 (E), U6.9 (E), U10.14 (~OUT9)
/O43: U5.8 (D), U6.8 (D), U10.15 (~OUT10)
/O44: U5.7 (R), U6.7 (R), U10.16 (~OUT11)
/O45: U5.6 (G), U6.6 (G), U10.17 (~OUT12)
/O46: U5.3 (S), U6.3 (S), U10.18 (~OUT13)
/O47: U5.2 (T), U6.2 (T), U10.19 (~OUT14)
/O48: U5.1 (F), U6.1 (F), U10.20 (~OUT15)
/RST: J2.5 (~RST), R3.2, U7.29 (PC6/~RESET)
/RX: J1.5, U7.30 (PD0)
/SCK: J2.3 (SCK), U7.17 (PB5)
/TX: J1.4, U7.31 (PD1)
GND: C1.2, C2.2, C3.1, C4.1, C5.2, C6.2, C7.2, C8.2, J1.1, J2.6 (GND), R5.1, R6.1, R7.1, TP4.1, U7.3 (GND), U7.5 (GND), U7.21 (AGND), U8.1 (GND), U9.1 (GND), U10.1 (GND)
unnamed: TP2.1, U7.12 (PB0)
unnamed: TP3.1, U7.13 (PB1)
unnamed: TP5.1, U7.14 (PB2)
unnamed: C1.1, U7.7 (PB6/XTAL1), Y1.1
unnamed: C2.1, U7.8 (PB7/XTAL2), Y1.2
unnamed: TP6.1, U7.11 (PD7)
unnamed: R5.2, U8.23 (R-EXT)
unnamed: U8.22 (SDO), U9.2 (SDI)
unnamed: R6.2, U9.23 (R-EXT)
unnamed: R7.2, U10.23 (R-EXT)
unnamed: U9.22 (SDO), U10.2 (SDI)
VD: C5.1, J1.2, Q1.2 (S), Q2.2 (S), Q3.2 (S), Q4.2 (S)

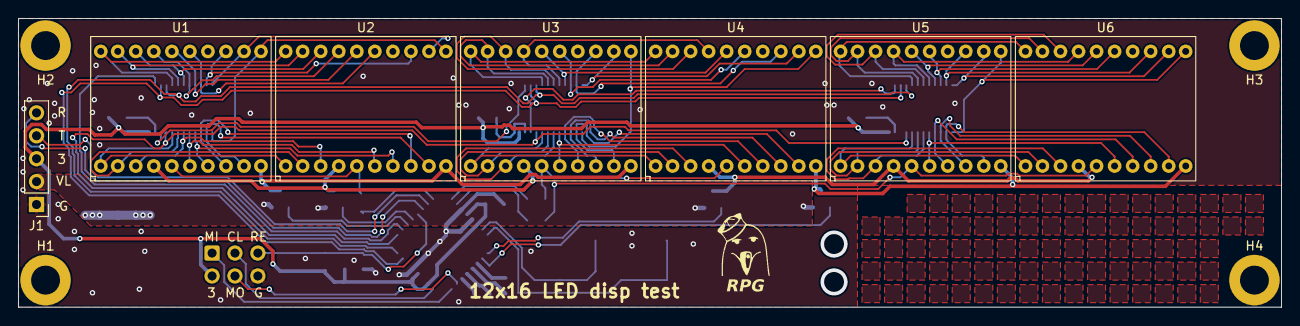
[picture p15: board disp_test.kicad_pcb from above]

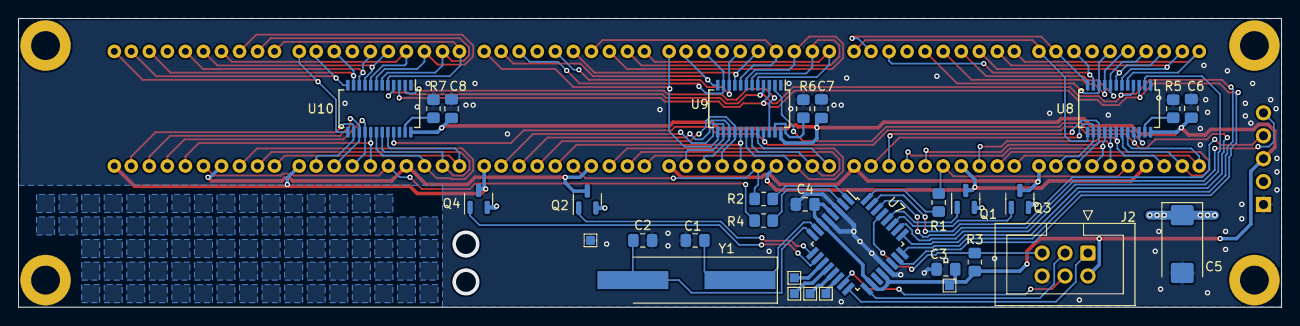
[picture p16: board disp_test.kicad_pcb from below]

Board: 2 copper layers, 140.0 x 32.0 mm, 43 parts (31 on the bottom side), 86 nets.

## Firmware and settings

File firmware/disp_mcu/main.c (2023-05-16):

#define F_CPU 4000000UL

#define USART_BAUDRATE 9600
#define BAUD_PRESCALE (((F_CPU / (USART_BAUDRATE * 16UL))) - 1)

#include <avr/io.h>
#include <util/delay.h>
#include<avr/interrupt.h>
#include <avr/pgmspace.h>

#define BIT_SET(a,b) ((a) |= (1ULL<<(b)))
#define BIT_CLEAR(a,b) ((a) &= ~(1ULL<<(b)))
#define BIT_FLIP(a,b) ((a) ^= (1ULL<<(b)))
#define BIT_CHECK(a,b) (!!((a) & (1ULL<<(b))))        // '!!' to make sure this returns 0 or 1

#define     SR_DI_H    BIT_SET(PORTC,3)
#define     SR_DI_L    BIT_CLEAR(PORTC,3)
#define     SR_CLK_H   BIT_SET(PORTC,0)
#define     SR_CLK_L   BIT_CLEAR(PORTC,0)
#define     SR_LE_H    BIT_SET(PORTC,1)
#define     SR_LE_L    BIT_CLEAR(PORTC,1)
#define     SR_OE_H    BIT_SET(PORTC,2)
#define     SR_OE_L    BIT_CLEAR(PORTC,2)
#define     DA_1_H     BIT_SET(PORTC,5)
#define     DA_1_L     BIT_CLEAR(PORTC,5)
#define     DA_2_H     BIT_SET(PORTC,4)
#define     DA_2_L     BIT_CLEAR(PORTC,4)
#define     DA_3_H     BIT_SET(PORTD,5)
#define     DA_3_L     BIT_CLEAR(PORTD,5)
#define     DA_4_H     BIT_SET(PORTD,6)
#define     DA_4_L     BIT_CLEAR(PORTD,6)

#define     DP_1_H     BIT_SET(PORTD,2)
#define     DP_1_L     BIT_CLEAR(PORTD,2)
#define     DP_2_H     BIT_SET(PORTD,3)
#define     DP_2_L     BIT_CLEAR(PORTD,3)
#define     DP_3_H     BIT_SET(PORTD,4)
#define     DP_3_L     BIT_CLEAR(PORTD,4)


//slighly altered from https://github.com/dmadison/LED-Segment-ASCII
const PROGMEM uint16_t ASCII[96] = {
	0b0000000000000000, /* (space) */
	0b0000000000001100, /* ! */
	0b0000001000000100, /* " */
	0b1010101000111100, /* # */
	0b1010101010111011, /* $ */
	0b1110111010011001, /* % */
	0b1001001101110001, /* & */
	0b0000001000000000, /* ' */
	0b0001010000000000, /* ( */
	0b0100000100000000, /* ) */
	0b1111111100000000, /* * */
	0b1010101000000000, /* + */
	0b0100000000000000, /* , */
	0b1000100000000000, /* - */
	0b0001000000000000, /* . */
	0b0100010000000000, /* / */
	0b0100010011111111, /* 0 */
	0b0000010000001100, /* 1 */
	0b1000100001110111, /* 2 */
	0b0000100000111111, /* 3 */
	0b1000100010001100, /* 4 */
	0b1001000010110011, /* 5 */
	0b1000100011111011, /* 6 */
	0b0000000000001111, /* 7 */
	0b1000100011111111, /* 8 */
	0b1000100010111111, /* 9 */
	0b0010001000000000, /* : */
	0b0100001000000000, /* ; */
	0b1001010000000000, /* < */
	0b1000100000110000, /* = */
	0b0100100100000000, /* > */
	0b0010100000000111, /* ? */
	0b0000101011110111, /* @ */
	0b1000100011001111, /* A */
	0b0010101000111111, /* B */
	0b0000000011110011, /* C */
	0b0010001000111111, /* D */
	0b1000000011110011, /* E */
	0b1000000011000011, /* F */
	0b0000100011111011, /* G */
	0b1000100011001100, /* H */
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
	0b0000000000000000, /* (del) */
};

uint16_t segment_bitmap[12];
uint8_t disp_msg[12];
uint8_t disp_msg_tmp[12];
uint8_t anode_act=0;


uint16_t segment_order (uint16_t in)
	{
	uint16_t out=0;
	if (in&(1<<0)) out|=(1<<6);
	if (in&(1<<1)) out|=(1<<8);
	if (in&(1<<2)) out|=(1<<3);
	if (in&(1<<3)) out|=(1<<10);
	if (in&(1<<4)) out|=(1<<9);
	if (in&(1<<5)) out|=(1<<15);
	if (in&(1<<6)) out|=(1<<12);
	if (in&(1<<7)) out|=(1<<5);
	if (in&(1<<8)) out|=(1<<1);
	if (in&(1<<9)) out|=(1<<2);
	if (in&(1<<10)) out|=(1<<7);
	if (in&(1<<11)) out|=(1<<4);
	if (in&(1<<12)) out|=(1<<11);
	if (in&(1<<13)) out|=(1<<13);
	if (in&(1<<14)) out|=(1<<14);
    if (in&(1<<15)) out|=(1<<0);
	return out;
	}

void set_sr_16 (uint16_t data)
{
unsigned char i;
for (i=0;i<16;i++)
	{
	if ((data&0x8000)==0)
		{
		SR_DI_L;
		}
	else
		{
		SR_DI_H;
		}
	SR_CLK_H;
	data = data << 1;
	SR_CLK_L;
	}
}

void set_sr_3x16 (uint16_t data1, uint16_t data2, uint16_t data3)
{
set_sr_16(data1);
set_sr_16(data2);
set_sr_16(data3);
_delay_us(10);
SR_LE_H;
_delay_us(10);
SR_LE_L;

}


void set_anode (uint8_t anode)
{
DA_1_H;
DA_2_H;
DA_3_H;
DA_4_H;
if (anode==0) DA_1_L;
if (anode==1) DA_2_L;
if (anode==2) DA_3_L;
if (anode==3) DA_4_L;
}


// timer0 overflow
ISR(TIMER0_OVF_vect) {
    TCNT0=220;
}

ISR (TIMER1_OVF_vect)    // Timer1 ISR
{
	set_anode(5);
	if (anode_act==0)
		{
		set_sr_3x16(segment_bitmap[10],segment_bitmap[4],segment_bitmap[2]);
		set_anode(0);
		}
	if (anode_act==1)
		{
		set_sr_3x16(segment_bitmap[11],segment_bitmap[5],segment_bitmap[3]);
		set_anode(1);
		}
	if (anode_act==2)
		{
		set_sr_3x16(segment_bitmap[8],segment_bitmap[6],segment_bitmap[0]);
		set_anode(2);
		}
	if (anode_act==3)
		{
		set_sr_3x16(segment_bitmap[9],segment_bitmap[7],segment_bitmap[1]);
		set_anode(3);
		}
	anode_act++;
	if (anode_act==4) anode_act=0;
	TCNT1 = 65488;
}

ISR(UART_RX_vect)
{
   char ReceivedByte;
   ReceivedByte = UDR; // Fetch the received byte value into the variable "ByteReceived"
   UDR = ReceivedByte; // Echo back the received byte back to the computer
}


void uart_tx (uint8_t data)
{
    while ((UCSRA & (1 << UDRE)) == 0) {};
    UDR = data;
}

uint8_t uart_rx_rdy (void)
    {
    if (UCSRA & (1 << RXC))
        return 1;
    else 
        return 0;
    }

uint8_t uart_rx_read (void)
    {
    return UDR;
    }

int main (void)
{
    uint8_t i,rx_rcvd;
    DDRB |= 0xFF; 
	DDRC |= 0xFF; 
	DDRD |= 0xFF; 
    UCSRB = (1 << RXEN) | (1 << TXEN);   // Turn on the transmission and reception circuitry
//    UCSRB |= (1 << RXCIE);
    UBRRH = (BAUD_PRESCALE >> 8); // Load upper 8-bits of the baud rate value into the high byte of the UBRR register
    UBRR = BAUD_PRESCALE; // Load lower 8-bits of the baud rate value into the low byte of the UBRR register
	SR_OE_L;
    TCNT1 = 63974;   // for 1 sec at 16 MHz	
	TCCR1A = 0x00;
    TCCR1B = (1<<CS10) | (1<<CS11);
    TCNT0=0x00;
    TCCR0 = (1<<CS02) | (1<<CS00);
	TIMSK=(1<<TOIE0) | (1<<TOIE1);
	sei();        // Enable global interrupts by setting global interrupt enable bit in SREG
    DP_1_H;
    DP_2_H;
    DP_3_H;
    for (i=0;i<12;i++) disp_msg[i] = '-';
    for (i=0;i<12;i++) disp_msg_tmp[i] = disp_msg[i];
    while(1) 
		{
		if (uart_rx_rdy()!=0)
			{
			rx_rcvd = uart_rx_read();
			if (rx_rcvd>(' '-1))
				{
				for (i=1;i<12;i++) disp_msg_tmp[i-1] = disp_msg_tmp[i];
				disp_msg_tmp[11] = rx_rcvd;
				}
			else
				{
				for (i=0;i<12;i++) disp_msg[i] = disp_msg_tmp[i];
				}
			}
        for (i=0;i<12;i++)
            {
            segment_bitmap[i] = segment_order(pgm_read_word (ASCII+disp_msg[i]-32));
            }
		}
}

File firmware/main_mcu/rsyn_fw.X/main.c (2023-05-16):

#include <xc.h>
#include <stdio.h>
#include <string.h>

const char idn_string[13] = "RSYN v 1.00\n\0";

#define		_XTAL_FREQ		64000000
#pragma config FEXTOSC = OFF    // External Oscillator mode Selection bits (Oscillator not enabled)
#pragma config RSTOSC = HFINTOSC_64MHZ// Power-up default value for COSC bits (HFINTOSC with HFFRQ = 64 MHz and CDIV = 1:1)
#pragma config CLKOUTEN = OFF   // Clock Out Enable bit (CLKOUT function is disabled)
#pragma config CSWEN = ON       // Clock Switch Enable bit (Writing to NOSC and NDIV is allowed)
#pragma config FCMEN = ON       // Fail-Safe Clock Monitor Enable bit (Fail-Safe Clock Monitor enabled)
#pragma config MCLRE = EXTMCLR  // Master Clear Enable bit (If LVP = 0, MCLR pin is MCLR; If LVP = 1, RE3 pin function is MCLR )
#pragma config PWRTE = ON       // Power-up Timer Enable bit (Power up timer enabled)
#pragma config LPBOREN = OFF    // Low-power BOR enable bit (ULPBOR disabled)
#pragma config BOREN = SBORDIS  // Brown-out Reset Enable bits (Brown-out Reset enabled , SBOREN bit is ignored)
#pragma config BORV = VBOR_2P45 // Brown Out Reset Voltage selection bits (Brown-out Reset Voltage (VBOR) set to 2.45V)
#pragma config ZCD = OFF        // ZCD Disable bit (ZCD disabled. ZCD can be enabled by setting the ZCDSEN bit of ZCDCON)
#pragma config PPS1WAY = OFF
#pragma config STVREN = ON      // Stack Full/Underflow Reset Enable bit (Stack full/underflow will cause Reset)
#pragma config DEBUG = OFF      // Debugger Enable bit (Background debugger disabled)
#pragma config XINST = OFF      // Extended Instruction Set Enable bit (Extended Instruction Set and Indexed Addressing Mode disabled)
#pragma config WDTCPS = WDTCPS_31// WDT Period Select bits (Divider ratio 1:65536; software control of WDTPS)
#pragma config WDTE = OFF       // WDT operating mode (WDT Disabled)
#pragma config WDTCWS = WDTCWS_7// WDT Window Select bits (window always open (100%); software control; keyed access not required)
#pragma config WDTCCS = SC      // WDT input clock selector (Software Control)


#define	USART1_BAUD	9600
#define	USART1_BRG	((_XTAL_FREQ/64)/USART1_BAUD)-1
#define	USART2_BAUD 9600
#define	USART2_BRG	((_XTAL_FREQ/64)/USART2_BAUD)-1

typedef union
{
struct
 {
    unsigned k1:1;
    unsigned k2:1;
    unsigned k3:1;
    unsigned k4:1;
    unsigned k5:1;
    unsigned k6:1;
    unsigned k7:1;
 };
uint8_t  CHAR;
}key_var;

key_var keys_new,keys_old,keys;

void tx2_char (char data)
	{
	while (PIR3bits.TX2IF==0);
	TX2REG = data;
	}

void tx1_char (char data)
	{
	while (PIR3bits.TX1IF==0);
	TX1REG = data;
	}

void tx2_chars (char * data)
	{
	while (*data) 
		tx2_char(*data++);
	}

void tx1_chars (char * data)
	{
	while (*data) 
		tx1_char(*data++);
	}


char tx_str[20];
unsigned char var1;


void set_u2_pps (unsigned char uart_cfg)
	{
	GIE = 0;
    PPSLOCK = 0x55;
    PPSLOCK = 0xAA;
    PPSLOCKbits.PPSLOCKED = 0;
	if (uart_cfg==0)
		{
		RB0PPS = 0x0B;	//TX2
		RB2PPS = 0;
		}
	else
		{
		RB0PPS = 0;
		RB2PPS = 0x0B;	//TX2		
		}
    PPSLOCK = 0x55;
    PPSLOCK = 0xAA;
    PPSLOCKbits.PPSLOCKED = 1;
	GIE = 1;
	}

unsigned char key_read (void)
	{
	return PORTC&0x0F;
	}


typedef struct range
	{
	float setval_max;
	float setval_min;
	float range_mul;
	} 
range;

typedef struct cal_single
	{
	float cal_offset;
	float cal_gain;
	} 
cal_single;


unsigned long dacval;
unsigned int setval_exp;
unsigned char range_act,blink_on;
float setval,setval_inc,setval_temp;
float setval_inc_table [5] = {0.1,0.01,0.001,0.0001,0.00001};

#define RANGE_NUM	2
range ranges[RANGE_NUM];
cal_single cal[RANGE_NUM];
char rcvd_str[40],rcvd_ptr;
volatile char rcvd_flag;


void display_set_value (float val, unsigned char exp, unsigned char range, unsigned char blink_en)
	{
	static unsigned char blink;
	blink++;
	if (range==0) sprintf (tx_str,"%07.4f kOhm\n",val);
	if (range==1) sprintf (tx_str,"%07.3f kOhm\n",val);
	if ((blink&0x02)&&(blink_en!=0)) 
		{
		if (exp>range) exp++;
		tx_str[exp+1]=' ';
		}
	set_u2_pps(0);
	__delay_ms(1);
	tx2_chars(tx_str);
	__delay_ms(5);
	}


void __interrupt() ISR(void)
{
char temp;
if (RC1IF)
	{
	RC1IF = 0;
	temp = RC1REG;
	if (temp<0x20)
		{
		if (rcvd_ptr>0)
			{
			rcvd_str[rcvd_ptr] = 0;
			rcvd_flag = 1;
			rcvd_ptr = 0;
			}
		}
	else
		{
		rcvd_str[rcvd_ptr++] = temp;
		}
	if (rcvd_ptr>=sizeof(rcvd_str)) rcvd_ptr = 0;
	}
}

unsigned char ee_read(unsigned int address)
	{
	NVMCON1=0;				//ensure CFGS=0 and EEPGD=0
	NVMADRL = address&0xFF;
	//EEADRH= (address>>8)&0x03;
	NVMCON1bits.RD = 1;
	NVMCON1=0x80;
	return(NVMDAT);
	}


void ee_write(unsigned int address,unsigned char data)
	{
	unsigned char SaveInt;
	SaveInt=INTCON;			//save interrupt status
	NVMCON1=0;				//ensure CFGS=0 and EEPGD=0
	NVMCON1bits.WREN = 1;	//enable write to EEPROM
	NVMADRL = address&0xFF;
	//EEADRH= (address>>8)&0x03;
	NVMDAT = data;			//and data
	INTCONbits.GIE=0;		//No interrupts
	NVMCON2 = 0x55;			//required sequence #1
	NVMCON2 = 0xAA;			//#2
	NVMCON1bits.WR = 1;		//#3 = actual write
	__delay_us(100);
	INTCON=SaveInt;			//restore interrupts
	while(NVMCON1bits.WR);	//wait until finished
	NVMCON1bits.WREN = 0;	//disable write to EEPROM
	NVMCON1=0x80;
	}

void ee_save_calib(cal_single * cal_arr)
	{
	volatile unsigned char i,addr,temp;
	unsigned char * c_ptr;
	c_ptr = (unsigned char *)(cal_arr);
	addr = 0;
	for (i=0;i<4*4;i++)
		{
		temp = *c_ptr++;
		ee_write(addr++,temp);
		}
	}

void ee_load_calib(cal_single * cal_arr)
	{
	volatile unsigned char i,addr,temp;
	unsigned char * c_ptr;
	c_ptr = (unsigned char *)(cal_arr);
	addr = 0;
	for (i=0;i<4*4;i++)
		{
		temp = ee_read(addr++);
		*c_ptr = temp;
		*c_ptr++;
		}
	
	for (i=0;i<2;i++)
		{
		if ((cal[i].cal_gain > 1000000.0)|(cal[i].cal_gain < -1000000.0)) cal[i].cal_gain = 12345.0;
		if ((cal[i].cal_offset > 10.0)|(cal[i].cal_offset < -10.0)) cal[i].cal_offset = 0.0;
		}
	}
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
